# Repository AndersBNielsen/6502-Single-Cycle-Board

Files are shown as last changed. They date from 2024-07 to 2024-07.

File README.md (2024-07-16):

# 6502 Single Cycle Board
 Easy 6502 Single Stepping based on Steve Wozniak's circuit in the Apple-1 Manual

Hook up 5V+GND and the three signals to your 6502 CPU and watch it halt after each instruction - even running at several MHz. No matter if it's an NMOS 6502 from 1975 or a CMOS from 2024. 

You can either order the PCB from JLCPCB (shipping world wide, see below) who kindly sponsored this project or order a ready made board direct from the creator here(shipping to 51 countries): https://www.imania.dk/index.php?cPath=204&sort=5a&language=en

6502 Single Cycle Board

## Ordering a PCB worldwide
This project is kindly sponsored by JLCPCB. They offer cheap, professional looking PCBs and super fast delivery.

Step 1: Get the gerber file zip package from this repo
https://github.com/AndersBNielsen/6502-Single-Cycle-Board/blob/main/6502SCB.zip

Step 2: Upload to JLCPCB [https://jlcpcb.com/?from=Anders_N](https://jlcpcb.com/?from=Anders_N)

Upload

Step 3: Pick your color, surface finish and order.

Select settings

Save your choice

You can use these affiliate links to get a board for $2 and also get $54 worth of New User Coupons at: https://jlcpcb.com/?from=Anders_N

And in case you also want to order a 3D-printed case you can use this link. 
How to Get a $7 3D Printing Coupon: [https://jlc3dp.com/?from=Anders_N](https://jlc3dp.com/?from=Anders_N)

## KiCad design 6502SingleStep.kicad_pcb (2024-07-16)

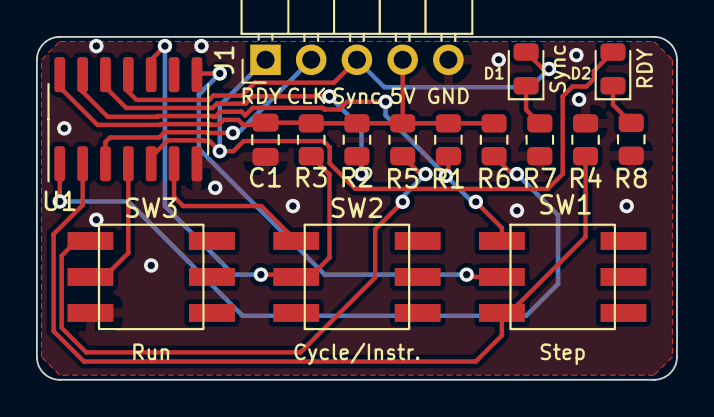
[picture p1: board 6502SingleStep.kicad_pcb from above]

Board: 2 copper layers, 35.6 x 19.0 mm, 16 parts (0 on the bottom side), 16 nets.

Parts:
C1: C_Small; C_0805_2012Metric
D1, D2: LED; LED_0805_2012Metric
J1: Conn_01x05_Male; PinHeader_1x05_P2.54mm_Horizontal
R1, R2, R3, R5, R6, R7, R8: 4k7; R_0805_2012Metric
R4: 300; R_0805_2012Metric
SW1: Step; XKB5858
SW2: Single Instruction; XKB5858
SW3: RUN; XKB5858
U1: 74HC74; SO-14_3.9x8.65mm_P1.27mm

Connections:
+5V: C1.1, J1.4, R1.1, R2.1, R3.1, R5.1, R6.1, U1.14 (VCC)
CLK: J1.2, U1.3 (C)
GND: C1.2, J1.5, R4.2, R7.2, R8.2, SW3.3 (C), U1.7 (GND)
unnamed: D1.1 (K), R7.1
unnamed: D2.1 (K), R8.1
unnamed: R1.2, SW1.1 (A), U1.13 (~R)
unnamed: R2.2, U1.12 (D)
unnamed: R3.2, SW2.2 (B), U1.10 (~S)
unnamed: R4.1, SW1.3 (C), U1.2 (D)
unnamed: R5.2, SW3.1 (A)
unnamed: R6.2, U1.1 (~R)
unnamed: SW1.2 (B), U1.8 (~Q)
unnamed: SW2.1 (A), U1.6 (~Q)
unnamed: SW3.2 (B), U1.4 (~S)
RDY: D2.2 (A), J1.1, U1.5 (Q)
SYNC: D1.2 (A), J1.3, U1.11 (C)
